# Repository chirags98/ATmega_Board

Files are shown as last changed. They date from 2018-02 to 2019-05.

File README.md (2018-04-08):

# ATmega_Board
This is a design to create a general purpose uC board using a ATmega328p microcontroller

Find the BOM (Bill of materials) on https://drive.google.com/open?id=1ma9ChhY5GpuYgg1Ucf6gE6C5UKoa5oTefCcq_7sxWGw

Find the Documentation of the board on https://drive.google.com/open?id=1ZgfvmyehAIBZDk0_nPWmhZg0xXYO81bvEzHlQfDXWbA

Find the example codes on https://github.com/chirags98/ATmega328-Example-Codes

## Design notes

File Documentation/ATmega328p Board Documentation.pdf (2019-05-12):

# ATmega Board Documentation

Objective | 2
Features | 2
Overview of using the board | 3
How to upload the Blink code for the first time | 3
Installing Atmel Studio | 3
Installing the drivers for USBasp | 4
Option 1: With Zadig | 4
Option 2: Without Zadig | 4
USBasp programmer | 5
Programming using SinaProg | 5
Programming with Arduino | 6
Steps to program using Arduino IDE | 6
Steps to burning the bootloader | 6
Serial Communication | 7
Installing FTDI driver | 7
Fuse settings on a new ATmega 328p | 8
ATmega to LCD mapping | 8
ATmega board to Arduino mapping | 8
Chirag Shah | 08/Apr/2018 | 1

# Objective

The objective of this document is to give an overview of the ATmega board, what all software installations and pin configurations one should be aware off so that one can get started with using the board.

# Features

1. ATmega 328p microcontroller
2. Serial (Arduino) as well as ISP programmable
3. Onboard 3.3v regulator
4. Onboard 5v regulator
5. Input voltage range: 7-20v using the DC Jack
6. Port for and onboard 16x2 LCD

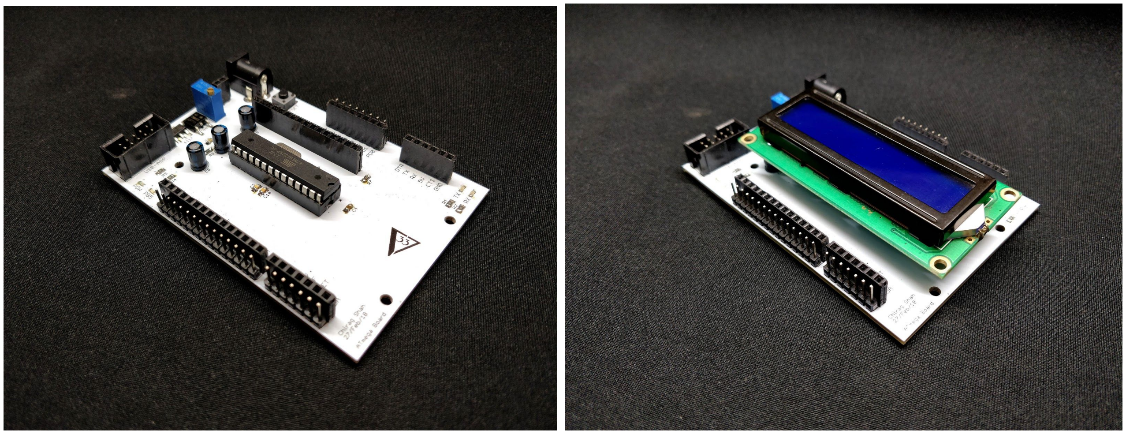
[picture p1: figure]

You can get the PCB design on https://github.com/chirags98/ATmega_Board

You can get the example codes for Atmel Studio on https://github.com/chirags98/ATmega328-Example-Codes

# Using the board

General instructions to use the board after the initial setup is complete are (detailed first-time instructions given below)
1. Write your code in Atmel studio (or use the example codes)
2. Build the solution to generate the hex file
3. Program the hex file on the board using USBasp programmer and SinaProg software (USBasp driver should be installed on the computer).

If you want to program the microcontroller using Arduino IDE, then
1. Write your code in the Arduino IDE
2. Select Arduino Nano and the COM port
3. Upload the code on the board using FTDI USB to Serial converter

Connect the FTDI directly to the header on the board ensuring that the pinout of the FTDI matches with the pinout on the board. Rx goes to Tx and Tx goes to Rx.

ATmega microcontroller should have the Arduino Nano bootloader on it. FTDI drivers should be installed.

# Uploading the Blink code for the first time

1. Download the example codes from here (https://github.com/chirags98/ATmega_Board)
2. You will need to download and install Atmel studio for writing new codes and to update existing codes (Procedure)
3. Disable the device driver signature enforcement and install the drivers for USB-ASP (Procedure)
4. Download SinaProg to upload the hex file to the microcontroller (Procedure)
5. Check the USB-ASP jumper (Procedure)
6. Upload the hex file. The hex file will be located in Blink>Blink>Debug>Blink.hex (Procedure)

## Installing Atmel Studio

Atmel Studio is the recommended IDE for embedded C programming for AVR microcontrollers.
Download and install the latest version from https://www.microchip.com/avr-support/atmel-studio-7

While installing only select support for 8-bit AVR microcontrollers.

## Installing the drivers for USBasp

### Option 1: With Zadig

1. Download Zadig software from http://chiragrshah.com/zadig_download Or from
https://zadig.akeo.ie/
2. Unzip and run zadig-2.4.exe
3. Click on Options>list all device
4. Select USBASP from the list
5. Select and install libusbK driver

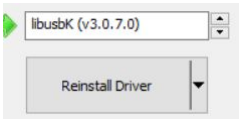
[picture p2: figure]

6. If this does not work try other drivers than libusbK

### Option 2: Without Zadig

The drivers for USPasp programmer are not digitally signed thus for security purposes windows has blocked the installation of unsigned drivers.

Get the USPasp drivers from https://drive.google.com/open?id=1goBblAIIR3vfRTkgHP2Q47yjxqCTrpaF

To disable the Driver Signature Enforcement for installing and using the drivers follow the steps given below
1. Recovery
2. Advanced startup>Restart Now
3. Troubleshoot
4. Advanced Options
5. Startup Settings
6. Restart
7. Disable Driver Signature Enforcement (press 7)

Use the steps given below for installing the drivers
1. Device Manager
2. USBasp

3. Update Driver
4. Browse my computer for driver software
5. Navigate and select the libusb_0.1.12.1 folder. (use libusb_0.1.10.1 if this doesn't work)
If the programmer stops working occasionally then you might need to disable the drivers again.

## USBasp programmer

1. Make sure the “Slow SCK” jumper is removed if available on your programmer
2. Make sure the switch/jumper is set to 5v and not 3.3v
3. Make sure the drivers are installed before trying to use the programmer

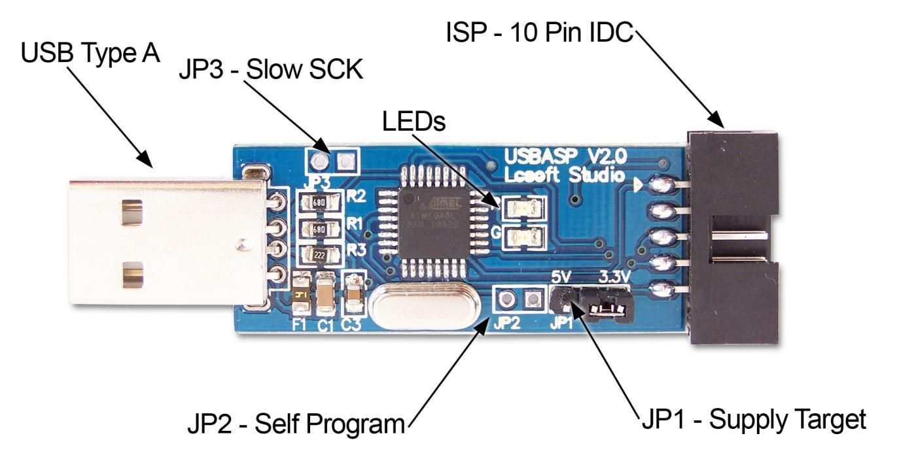
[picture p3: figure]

## Programming using SinaProg

Download SinaProg from
http://chiragrshah.com/download_sinaprog
1. Open the folder and run the application
2. Navigate to and select the .hex file of the project
3. Click on “Program flash”

# Programming with Arduino

This board can act exactly like an Arduino uno/nano. To program it with Arduino IDE make sure the microcontroller has bootloader on it. You cannot program it using an FTDI converter if it does not have a bootloader on it. To burn the bootloader follow the steps given below.

## Steps to program using Arduino IDE

1. Write your code in the Arduino IDE
2. Select Arduino Nano and the COM port
3. Connect the FTDI directly to the header on the board ensuring that the pinout of the FTDI matches with the pinout on the board. Rx goes to Tx and Tx goes to Rx.
4. Click on upload

Note: ATmega microcontroller should have the Arduino Nano bootloader on it. FTDI drivers should be installed.

## Steps to burning the bootloader

If you have a new ATmega328, you'll need to burn the bootloader onto it. You can do this using an Arduino board as an in-system program (ISP).
If the microcontroller already has the bootloader on it, you can skip this section.

To burn the bootloader, follow these steps:
1. Upload the ArduinoISP sketch onto your Arduino board. (You'll need to select the board and serial port from the Tools menu that correspond to your board.)
2. Connect the pins on Arduino to the pins on atmega board as shown on the table
3. Select "Arduino Duemilanove or Nano w/ ATmega328" from the Tools > Board menu.
4. Select "Arduino as ISP" from Tools > Programmer
5. Run Tools > Burn Bootloader
Pin on Arduino | Pin on target ATmega board
D13 | PB5
D12 | PB4
D11 | PB3
D10 | RESET
5V | 5V
GND | GND

Option 2: Use another ATmega board instead of an Arduino

Pin on master ATmega board | Pin on target ATmega board
PB5 | PB5
PB4 | PB4
PB3 | PB3
PB2 | RESET
5V | 5V
GND | GND

Further reference for this can be found at: https://www.Arduino.cc/en/Tutorial/ArduinoToBreadboard

## Serial Communication

If you want to interface your ATmega board to your computer via USB you will need a FTDI USB To TTL Serial Converter Adapter Module.

Your PC can communicate with the board via the serial port (also known as a UART or USART Serial). It communicates on digital pins 0 (RX) and 1 (TX) as well as with the computer via USB.

## Installing FTDI driver

FTDI USB to serial converter is required for USB to serial communication. Download the FTDI driver from http://www.ftdichip.com/Drivers/VCP.htm

# Fuse settings on a new ATmega 328p

If you are using a new ATmega IC you will need to program the fuse bits the first time.

The recommended settings for the fuse bits are
Lock Bits | x0F
High Fuse | xDA
Low fuse | xFF
Ext. Fuse | x05

Steps to program the fuse bits
1. Open SinaProg
2. Fuses > Advanced
3. Set the correct values and write (Try once again if you get a verification error) References:
http://www.engbedded.com/fusecalchttp://www.martyncurrey.com/Arduino-atmega-328p-fuse-settings/

# ATmega to LCD mapping

ATmega Board | LCD
PD2 | D7
PD3 | D6
PD4 | D5
PD5 | D4
PD6 | E
PD7 | RS

# ATmega board to Arduino mapping

This section gives the pin mappings between the ATmega to Arduino board
ATmega Board | Arduino
PD0/RX | D0/RX

PD1/TX | D1/TX
PD2 | D2
PD3 | D3
PD4 | D4
PD5 | D5
PD6 | D6
PD7 | D7
ATmega Board | Arduino
PC0 | A0
PC1 | A1
PC2 | A2
PC3 | A3
PC4/SDA | A4
PC5/SCL | A5
ATmega Board | Arduino
PB0 | D8
PB1 | D9
PB2 | D10
PB3/MOSI | D11
PB4/MISO | D12
PB5/SCK | D13

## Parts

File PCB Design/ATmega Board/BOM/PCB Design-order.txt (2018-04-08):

Order list for C:/Users/Chirag/Desktop/ATmega Design/ATmega_Board/PCB Design/ATmega Board/PCB Design.sch
Exported from EAGLE with DesignLink

Quantity	Value	Package	Order code	Manufacturer	Manuf. Code	Availability	Price (from)	Description
1	POWER_JACK	POWER_JACK_PTH	1310918	MULTICOMP	SPC21365	4534	75.3	MULTICOMP - SPC21365 - CONNECTOR, DC POWER, JACK, 5A
1	V_REG_LD1117VXXLD1117-SMD	SOT223	unknown					
1	5V	TO-252	unknown					
1	ATMEGA328P-PU	DIP254P762X457-28	1715487	MICROCHIP	ATMEGA328P-PU	823	120.45	MICROCHIP - ATMEGA328P-PU - MCU, 8BIT, ATMEGA, 20MHZ, DIP-28
3	10uf	E2,5-6	unknown					
3	.1uF	C0805K	unknown					
1	0.33µF	C0805K	unknown					
2	22pF	C0805K	unknown					
1	.1uf	C0805K	unknown					
1	50k	S64W	unknown					
1		1X02	unknown					
1		2X08	unknown					
2		2X06	unknown					
1		2X03	unknown					
1		2X07	unknown					
1	LCD-16X2NOSILK	LCD-16X2_NOSILK	unknown					
1	BLUE	LED-0603	unknown					
1	RED	LED-0603	unknown					
1	16MHz	HC49U70	unknown					
4	330	M0805	unknown					
1	10k	M0805	unknown					
1	220	M0805	unknown					
1		B3F-10XX	176432	OMRON ELECTRONIC COMPONENTS	B3F-1000	35652	14.54	OMRON ELECTRONIC COMPONENTS - B3F-1000 - SWITCH, SPNO, 0.05A, 24V, THT, 0.98N
2	Yellow	LED-0603	unknown					
1	6_PIN_SERIAL_CABLEPTH	FTDI_BASIC	unknown					
1	AVR_SPI_PROG_5X2PTH2	2X5-SHROUDED	unknown

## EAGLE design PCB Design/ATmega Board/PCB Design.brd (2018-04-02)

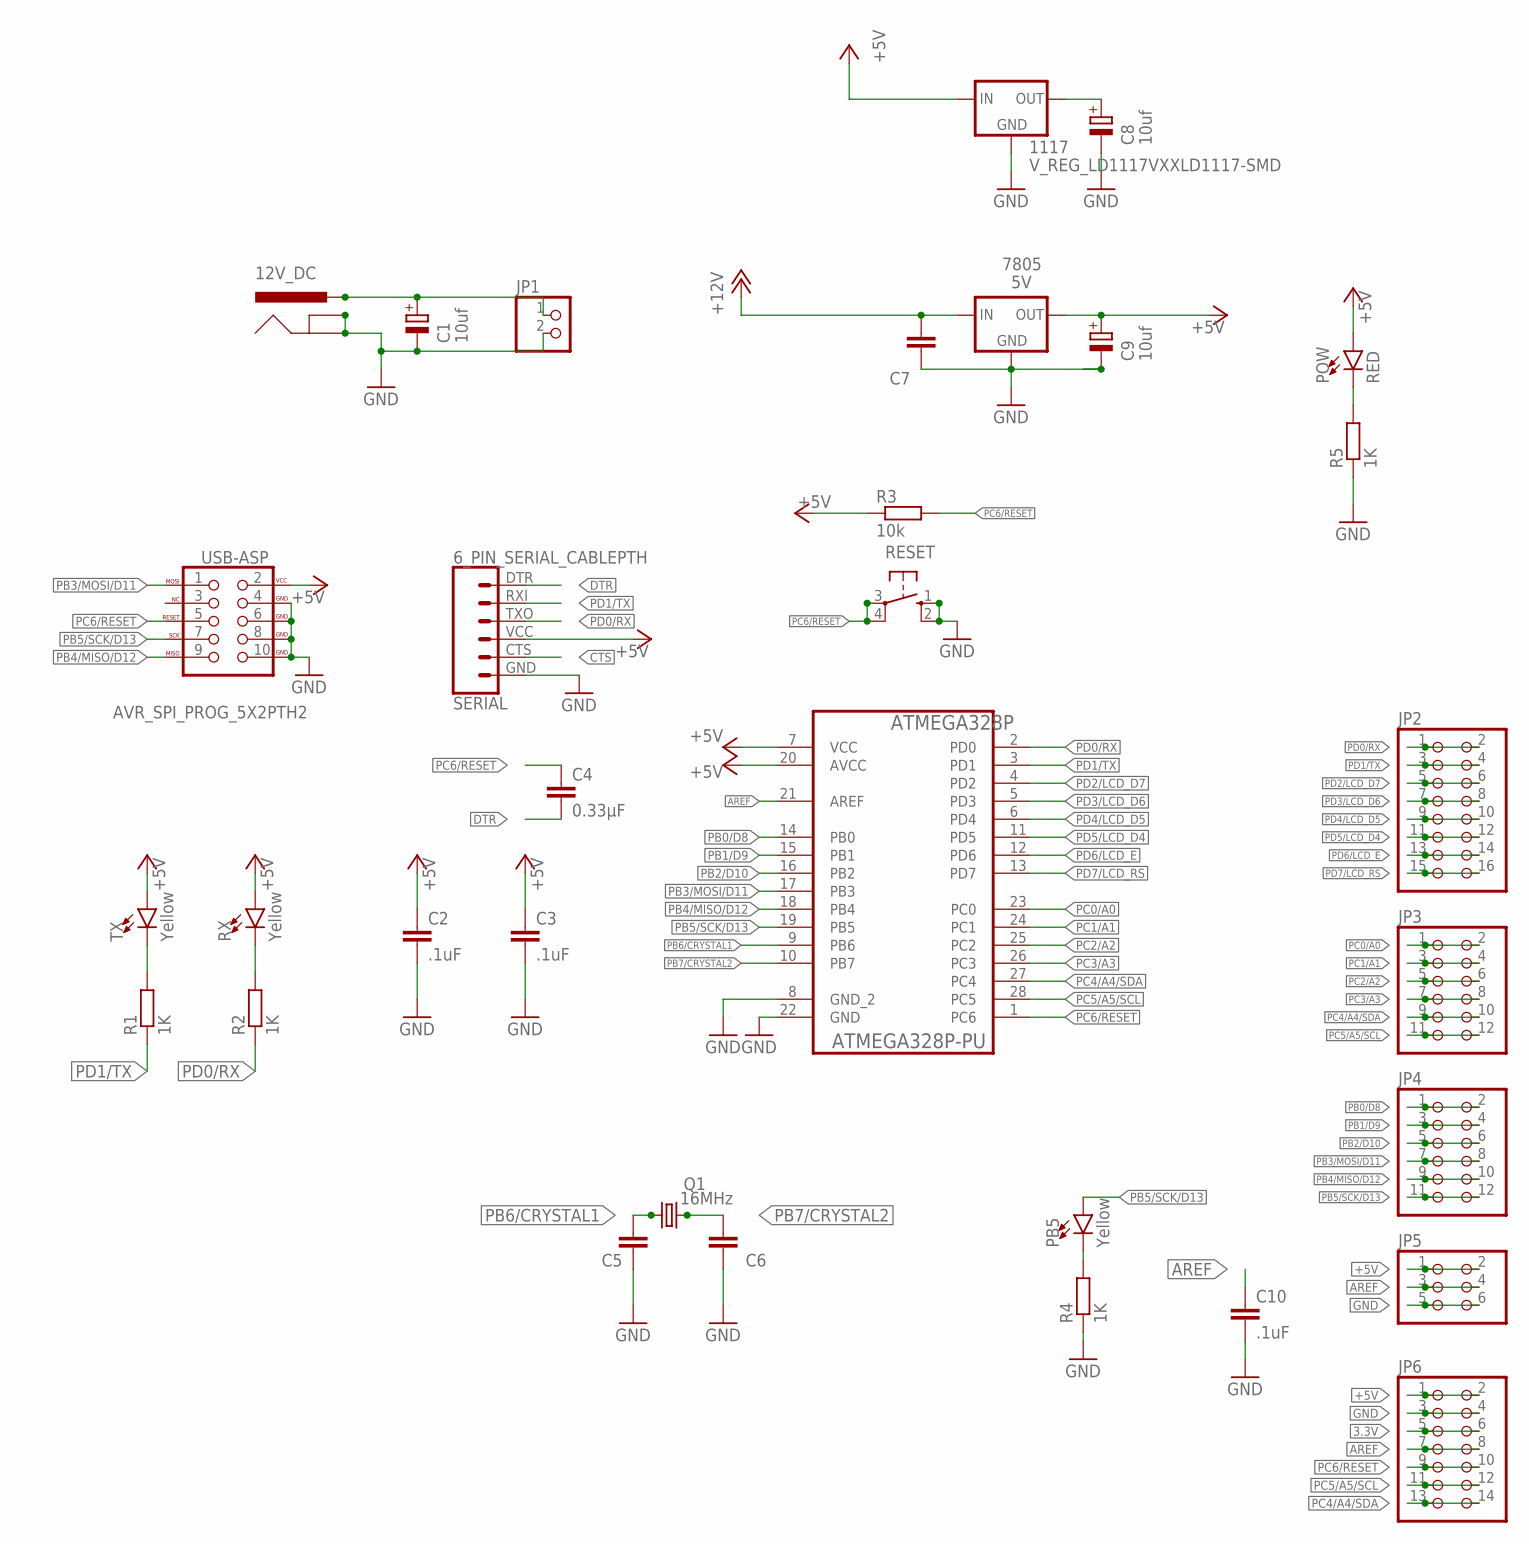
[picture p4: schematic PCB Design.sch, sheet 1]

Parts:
12V_DC: POWER_JACK; POWER_JACK_PTH; MPN SPC21365
1117: V_REG_LD1117VXXLD1117-SMD; SOT223
7805: 5V; TO-252
ATMEGA328P: ATMEGA328P-PU; DIP254P762X457-28
C1, C8, C9: 10uf; E2,5-6
C2, C3, C10: .1uF; C0805K
C4: 0.33µF; C0805K
C5, C6: 22pF; C0805K
C7: .1uf; C0805K
JP1: PINHD-1X2; 1X02
JP2: PINHD-2X8; 2X08
JP3, JP4: PINHD-2X6; 2X06
JP5: PINHD-2X3; 2X03
JP6: PINHD-2X7; 2X07
PB5: Yellow; LED-0603
POW: RED; LED-0603
Q1: 16MHz; HC49U70
R1, R2, R4, R5: 1K; M0805
R3: 10k; M0805
RESET: 10-XX; B3F-10XX
RX: Yellow; LED-0603
SERIAL: 6_PIN_SERIAL_CABLEPTH; FTDI_BASIC
TX: Yellow; LED-0603
USB-ASP: AVR_SPI_PROG_5X2PTH2; 2X5-SHROUDED

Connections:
3.3V: 1117.2 (OUT), C8.+, JP6.5, JP6.6
+5V: 1117.3 (IN), 7805.2 (OUT), ATMEGA328P.7 (VCC), ATMEGA328P.20 (AVCC), C2.1, C3.1, C9.+, JP5.1, JP5.2, JP6.1, JP6.2, POW.A, R3.1, RX.A, SERIAL.VCC (4), TX.A, USB-ASP.2 (VCC); also elsewhere on the board
+12V: 12V_DC.PWR, 7805.1 (IN), C1.+, C7.1, JP1.1
AREF: ATMEGA328P.21 (AREF), C10.1, JP5.3, JP5.4, JP6.7, JP6.8
CTS: SERIAL.CTS (5)
DTR: C4.2, SERIAL.DTR (1)
GND: 12V_DC.GND, 12V_DC.GNDBREAK, 1117.1 (GND), 7805.3 (GND), ATMEGA328P.8 (GND_2), ATMEGA328P.22 (GND), C1.-, C2.2, C3.2, C5.1, C6.1, C7.2, C8.-, C9.-, C10.2, JP1.2, JP5.5, JP5.6, JP6.3, JP6.4, R4.1, R5.1, RESET.1 (S), RESET.2 (S1), SERIAL.GND (6), USB-ASP.4 (GND), USB-ASP.6 (GND), USB-ASP.8 (GND), USB-ASP.10 (GND); also elsewhere on the board
unnamed: PB5.C, R4.2
unnamed: POW.C, R5.2
unnamed: R2.2, RX.C
unnamed: R1.2, TX.C
PB0/D8: ATMEGA328P.14 (PB0), JP4.1, JP4.2
PB1/D9: ATMEGA328P.15 (PB1), JP4.3, JP4.4
PB2/D10: ATMEGA328P.16 (PB2), JP4.5, JP4.6
PB3/MOSI/D11: ATMEGA328P.17 (PB3), JP4.7, JP4.8, USB-ASP.1 (MOSI)
PB4/MISO/D12: ATMEGA328P.18 (PB4), JP4.9, JP4.10, USB-ASP.9 (MISO)
PB5/SCK/D13: ATMEGA328P.19 (PB5), JP4.11, JP4.12, PB5.A, USB-ASP.7 (SCK)
PB6/CRYSTAL1: ATMEGA328P.9 (PB6), C5.2, Q1.1
PB7/CRYSTAL2: ATMEGA328P.10 (PB7), C6.2, Q1.2
PC0/A0: ATMEGA328P.23 (PC0), JP3.1, JP3.2
PC1/A1: ATMEGA328P.24 (PC1), JP3.3, JP3.4
PC2/A2: ATMEGA328P.25 (PC2), JP3.5, JP3.6
PC3/A3: ATMEGA328P.26 (PC3), JP3.7, JP3.8
PC4/A4/SDA: ATMEGA328P.27 (PC4), JP3.9, JP3.10, JP6.13, JP6.14
PC5/A5/SCL: ATMEGA328P.28 (PC5), JP3.11, JP3.12, JP6.11, JP6.12
PC6/RESET: ATMEGA328P.1 (PC6), C4.1, JP6.9, JP6.10, R3.2, RESET.3, RESET.4 (P1), USB-ASP.5 (RESET)
PD0/RX: ATMEGA328P.2 (PD0), JP2.1, JP2.2, R2.1, SERIAL.TXO (3)
PD1/TX: ATMEGA328P.3 (PD1), JP2.3, JP2.4, R1.1, SERIAL.RXI (2)
PD2/LCD_D7: ATMEGA328P.4 (PD2), JP2.5, JP2.6; also elsewhere on the board
PD3/LCD_D6: ATMEGA328P.5 (PD3), JP2.7, JP2.8; also elsewhere on the board
PD4/LCD_D5: ATMEGA328P.6 (PD4), JP2.9, JP2.10; also elsewhere on the board
PD5/LCD_D4: ATMEGA328P.11 (PD5), JP2.11, JP2.12; also elsewhere on the board
PD6/LCD_E: ATMEGA328P.12 (PD6), JP2.13, JP2.14; also elsewhere on the board
PD7/LCD_RS: ATMEGA328P.13 (PD7), JP2.15, JP2.16; also elsewhere on the board

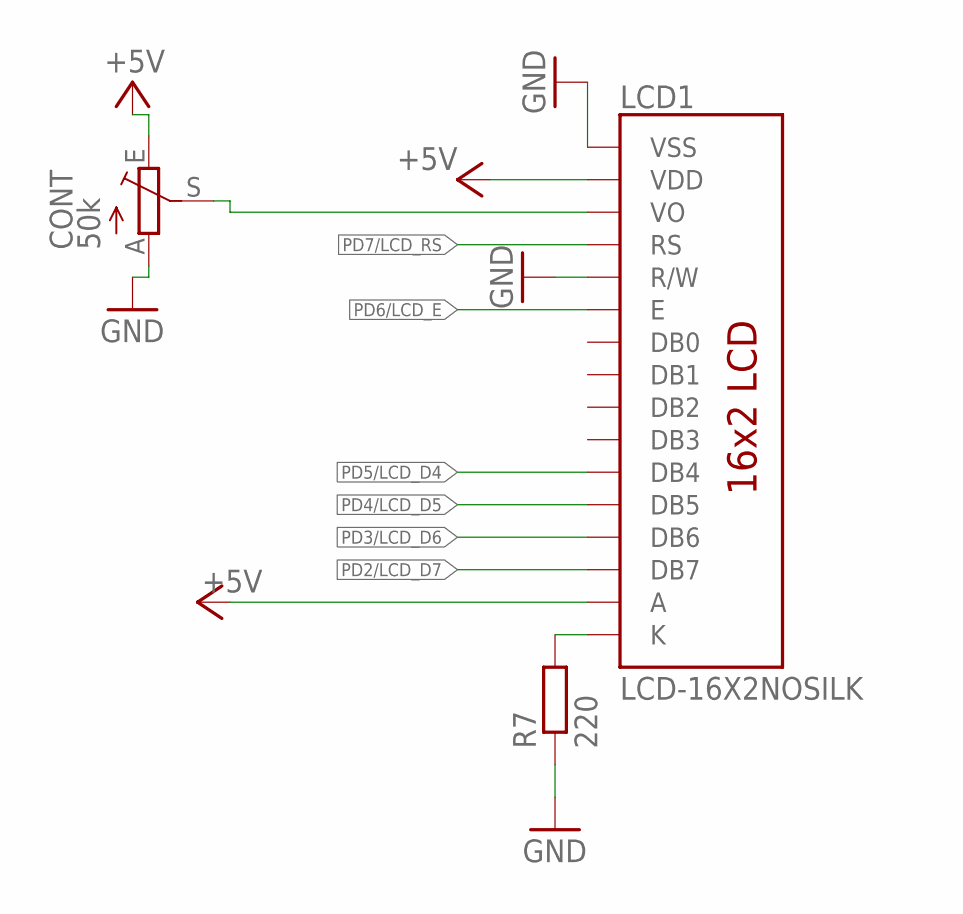
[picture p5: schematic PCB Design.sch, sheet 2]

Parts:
CONT: 50k; S64W
LCD1: LCD-16X2NOSILK; LCD-16X2_NOSILK
R7: 220; M0805

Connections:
+5V: CONT.E, LCD1.2 (VDD), LCD1.15 (A); also elsewhere on the board
GND: CONT.A, LCD1.1 (VSS), LCD1.5 (R/W), R7.1; also elsewhere on the board
unnamed: CONT.S, LCD1.3 (VO)
unnamed: LCD1.16 (K), R7.2
PD2/LCD_D7: LCD1.14 (DB7); also elsewhere on the board
PD3/LCD_D6: LCD1.13 (DB6); also elsewhere on the board
PD4/LCD_D5: LCD1.12 (DB5); also elsewhere on the board
PD5/LCD_D4: LCD1.11 (DB4); also elsewhere on the board
PD6/LCD_E: LCD1.6 (E); also elsewhere on the board
PD7/LCD_RS: LCD1.4 (RS); also elsewhere on the board

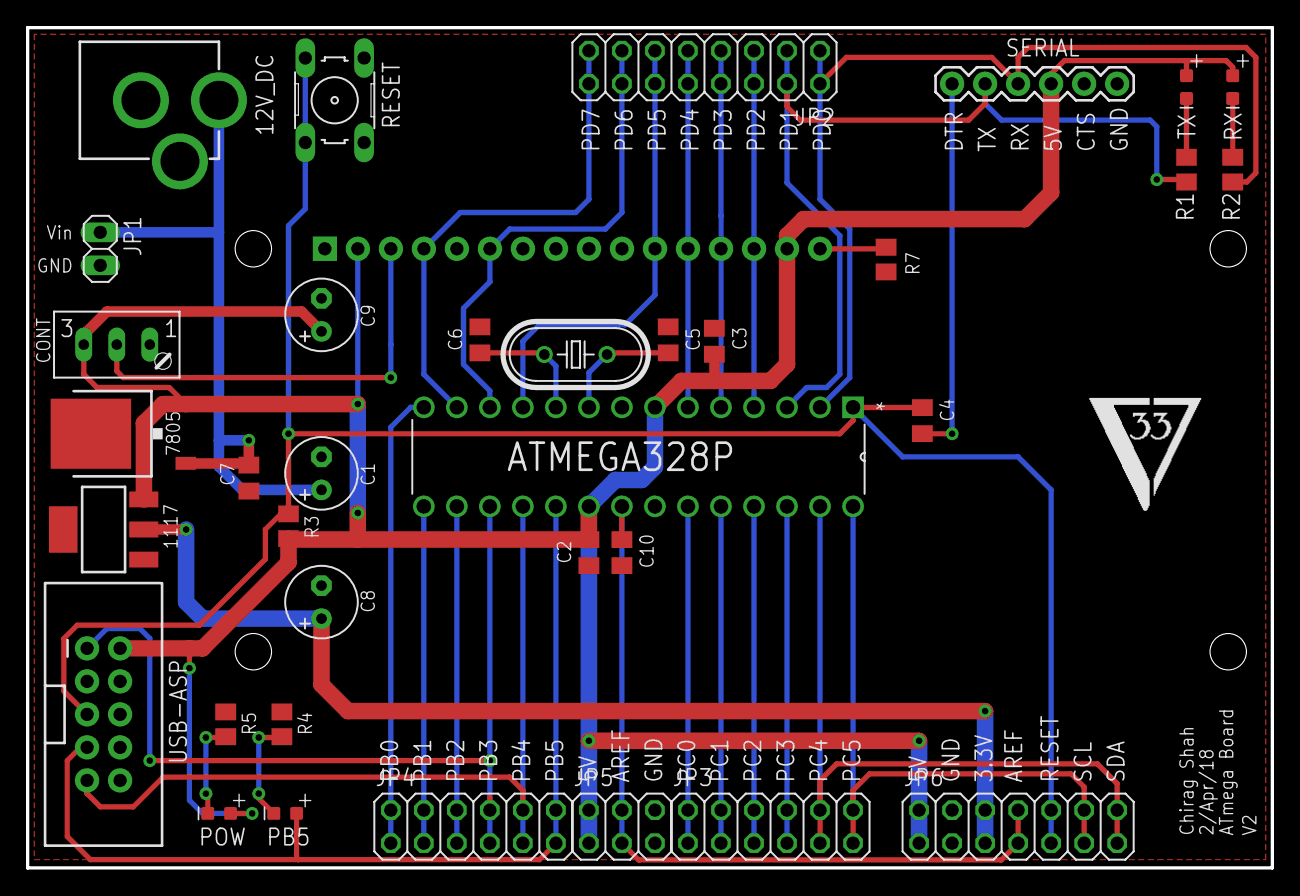
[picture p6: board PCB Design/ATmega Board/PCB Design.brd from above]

Board: 2 copper layers, 95.8 x 64.6 mm, 36 parts (0 on the bottom side), 35 nets.

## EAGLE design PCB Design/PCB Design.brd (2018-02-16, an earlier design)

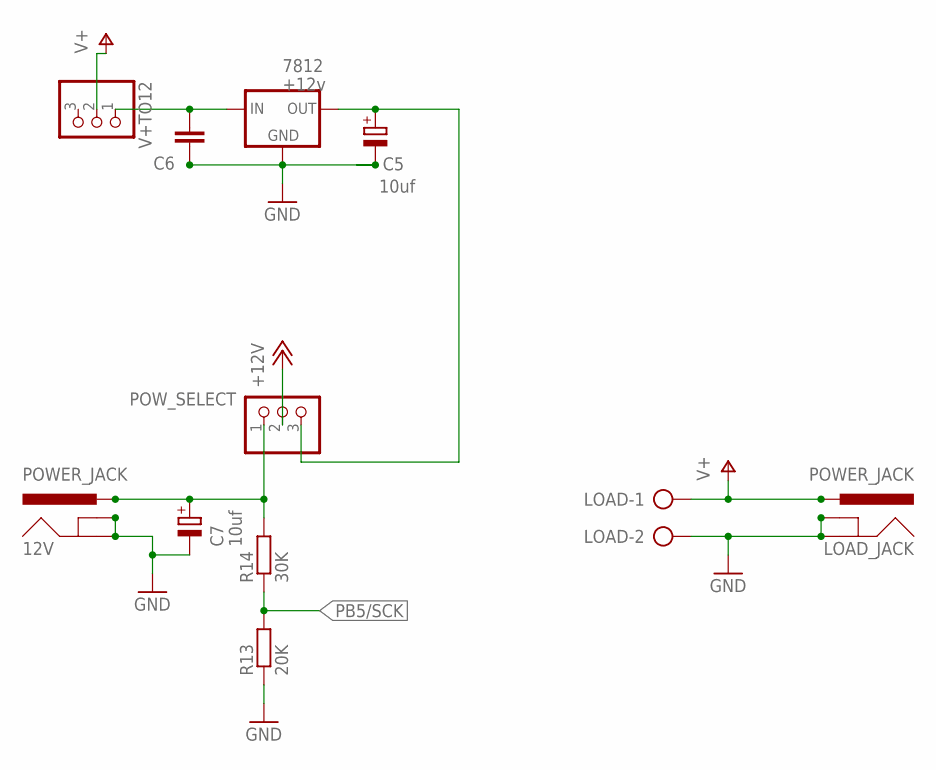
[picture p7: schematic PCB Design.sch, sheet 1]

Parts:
12V: POWER_JACK; POWER_JACK_PTH
7812: +12v; TO-252
C5, C7: 10uf; E2,5-6
C6: .1uF; C0805K
LOAD: AK500/2-H
LOAD_JACK: POWER_JACK; POWER_JACK_PTH
POW_SELECT: PINHD-1X3; 1X03
R13: 20K; M0805
R14: 30K; M0805
V+TO12: PINHD-1X3; 1X03

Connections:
12V_JACK_INPUT: 12V.PWR, C7.+, POW_SELECT.1, R14.2
12V_REG_O/P: 7812.2 (OUT), C5.+, POW_SELECT.3
+12V: POW_SELECT.2; also elsewhere on the board
GND: 12V.GND, 12V.GNDBREAK, 7812.3 (GND), C5.-, C6.2, C7.-, LOAD.2, LOAD_JACK.GND, LOAD_JACK.GNDBREAK, R13.1; also elsewhere on the board
unnamed: 7812.1 (IN), C6.1, V+TO12.1
PB5/SCK: R13.2, R14.1; also elsewhere on the board
V+: LOAD.1, LOAD_JACK.PWR, V+TO12.2

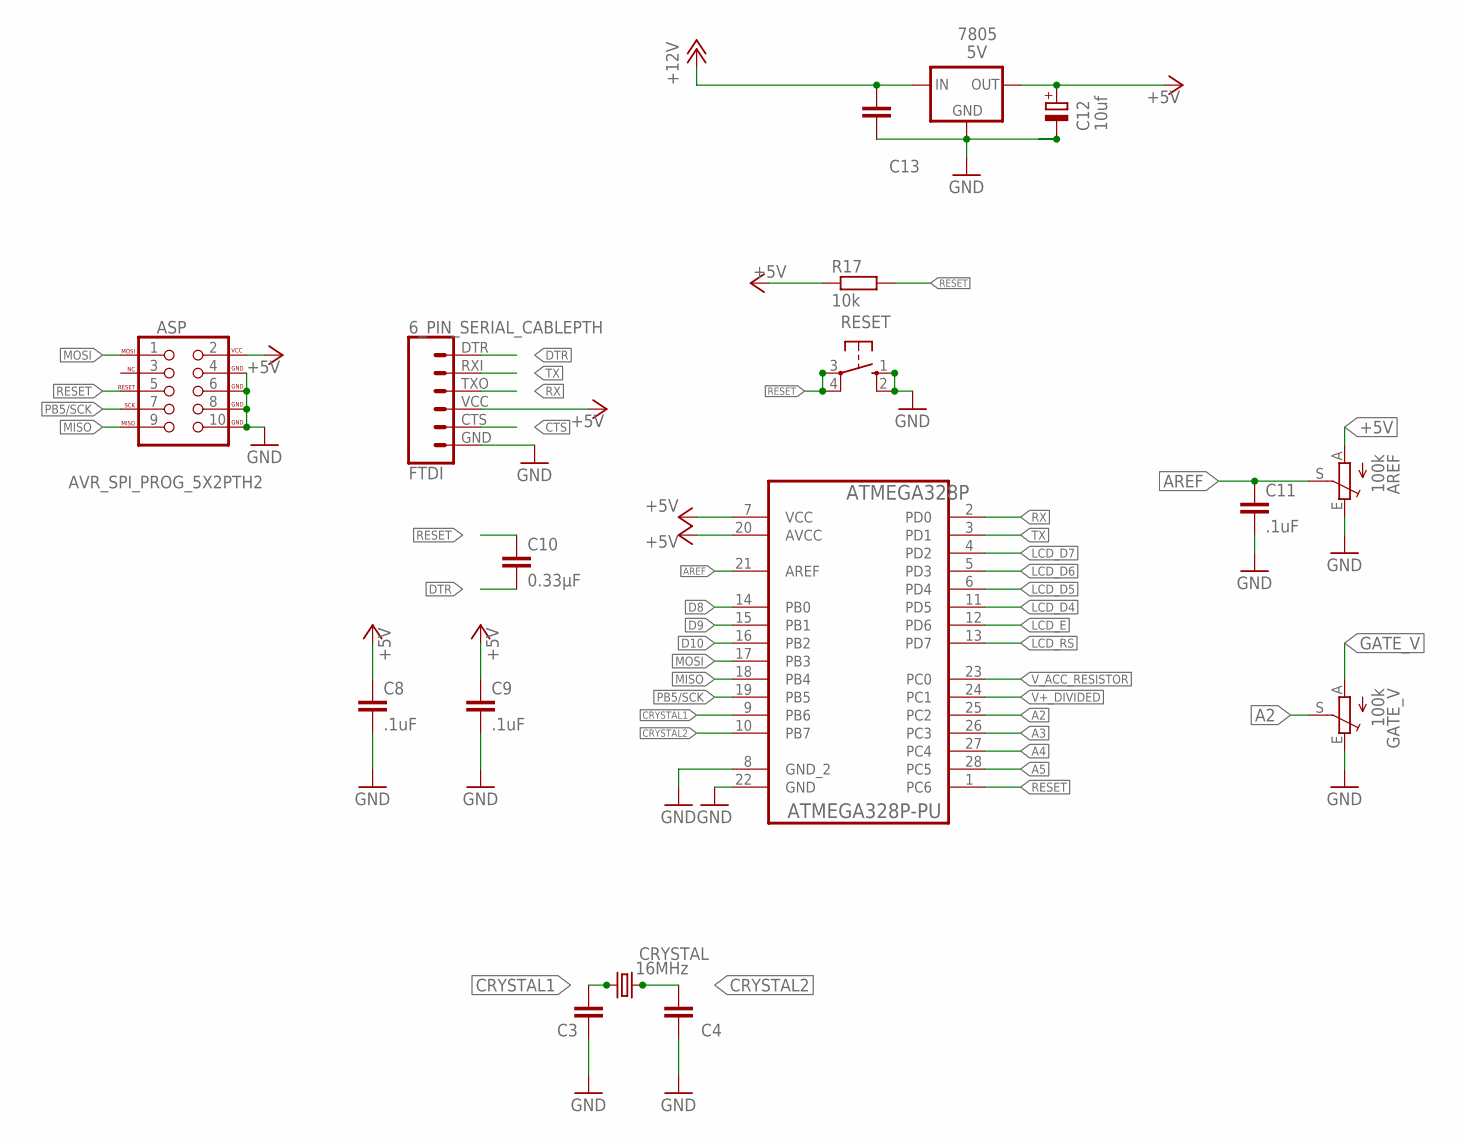
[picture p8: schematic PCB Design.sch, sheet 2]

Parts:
7805: 5V; TO-252
AREF: 100k; S64W
ASP: AVR_SPI_PROG_5X2PTH2; 2X5-SHROUDED
ATMEGA328P: ATMEGA328P-PU; DIP254P762X457-28
C3, C4: 22pF; C0805K
C8, C9, C11: .1uF; C0805K
C10: 0.33µF; C0805K
C12: 10uf; E2,5-6
C13: .1uf; C0805K
CRYSTAL: 16MHz; HC49U70
FTDI: 6_PIN_SERIAL_CABLEPTH; FTDI_BASIC
GATE_V: 100k; S64W
R17: 10k; M0805
RESET: 10-XX; B3F-10XX

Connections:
+5V: 7805.2 (OUT), AREF.A, ASP.2 (VCC), ATMEGA328P.7 (VCC), ATMEGA328P.20 (AVCC), C8.1, C9.1, C12.+, FTDI.VCC (4), R17.1; also elsewhere on the board
+12V: 7805.1 (IN), C13.1; also elsewhere on the board
A2: ATMEGA328P.25 (PC2), GATE_V.S
A3: ATMEGA328P.26 (PC3)
A4: ATMEGA328P.27 (PC4)
A5: ATMEGA328P.28 (PC5)
AREF: AREF.S, ATMEGA328P.21 (AREF), C11.1
CRYSTAL1: ATMEGA328P.9 (PB6), C3.2, CRYSTAL.1
CRYSTAL2: ATMEGA328P.10 (PB7), C4.2, CRYSTAL.2
CTS: FTDI.CTS (5)
D8: ATMEGA328P.14 (PB0)
D9: ATMEGA328P.15 (PB1)
D10: ATMEGA328P.16 (PB2)
DTR: C10.2, FTDI.DTR (1)
GATE_V: GATE_V.A
GND: 7805.3 (GND), AREF.E, ASP.4 (GND), ASP.6 (GND), ASP.8 (GND), ASP.10 (GND), ATMEGA328P.8 (GND_2), ATMEGA328P.22 (GND), C3.1, C4.1, C8.2, C9.2, C11.2, C12.-, C13.2, FTDI.GND (6), GATE_V.E, RESET.1 (S), RESET.2 (S1); also elsewhere on the board
LCD_D4: ATMEGA328P.11 (PD5); also elsewhere on the board
LCD_D5: ATMEGA328P.6 (PD4); also elsewhere on the board
LCD_D6: ATMEGA328P.5 (PD3); also elsewhere on the board
LCD_D7: ATMEGA328P.4 (PD2); also elsewhere on the board
LCD_E: ATMEGA328P.12 (PD6); also elsewhere on the board
LCD_RS: ATMEGA328P.13 (PD7); also elsewhere on the board
MISO: ASP.9 (MISO), ATMEGA328P.18 (PB4)
MOSI: ASP.1 (MOSI), ATMEGA328P.17 (PB3)
PB5/SCK: ASP.7 (SCK), ATMEGA328P.19 (PB5); also elsewhere on the board
RESET: ASP.5 (RESET), ATMEGA328P.1 (PC6), C10.1, R17.2, RESET.3, RESET.4 (P1)
RX: ATMEGA328P.2 (PD0), FTDI.TXO (3)
TX: ATMEGA328P.3 (PD1), FTDI.RXI (2)
V+_DIVIDED: ATMEGA328P.24 (PC1)
V_ACC_RESISTOR: ATMEGA328P.23 (PC0)

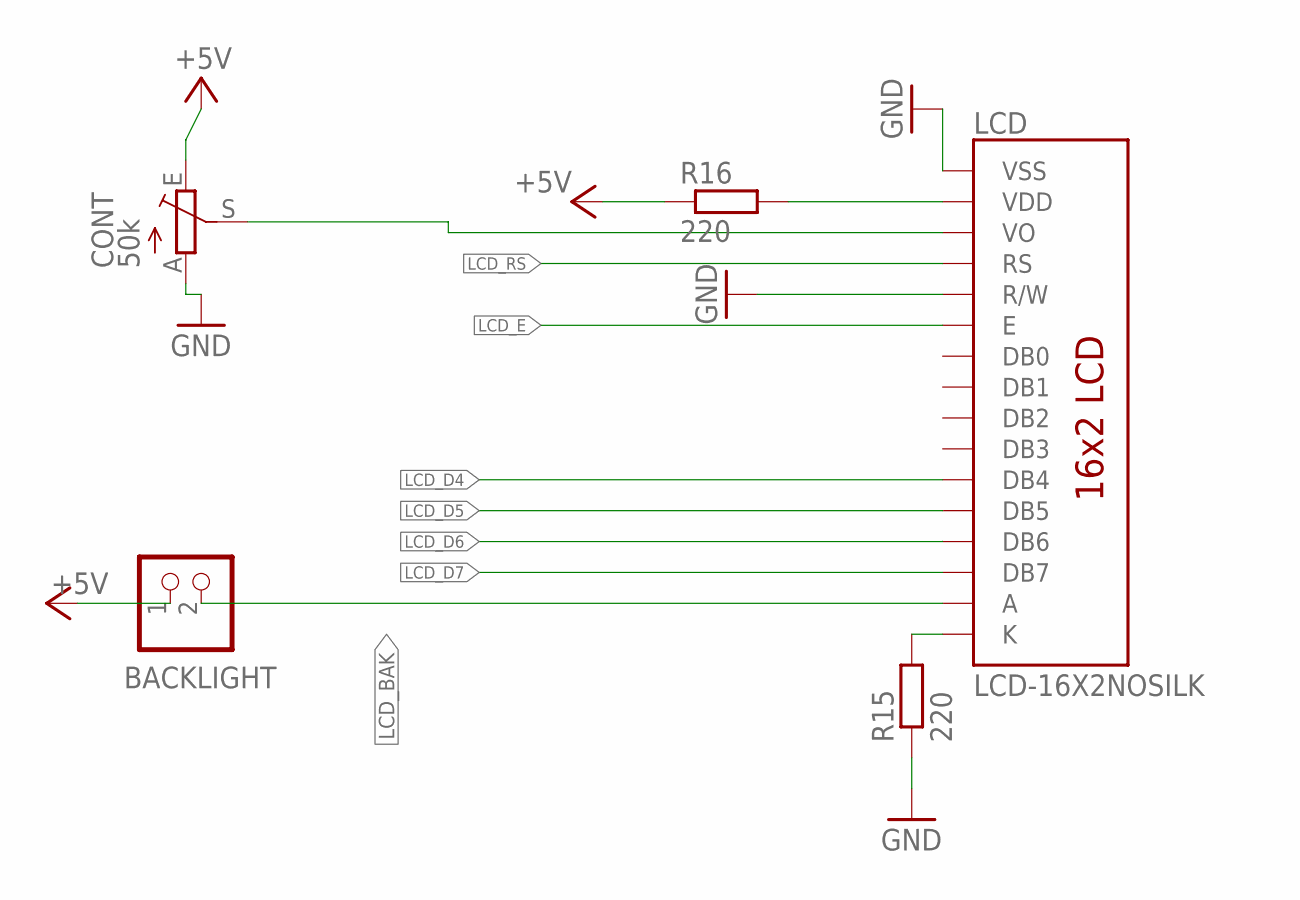
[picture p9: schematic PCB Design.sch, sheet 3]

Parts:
BACKLIGHT: PINHD-1X2; 1X02
CONT: 50k; S64W
LCD: LCD-16X2NOSILK; LCD-16X2_NOSILK
R15, R16: 220; M0805

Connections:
+5V: BACKLIGHT.1, CONT.E, R16.1; also elsewhere on the board
GND: CONT.A, LCD.1 (VSS), LCD.5 (R/W), R15.1; also elsewhere on the board
LCD_BAK: BACKLIGHT.2, LCD.15 (A)
LCD_D4: LCD.11 (DB4); also elsewhere on the board
LCD_D5: LCD.12 (DB5); also elsewhere on the board
LCD_D6: LCD.13 (DB6); also elsewhere on the board
LCD_D7: LCD.14 (DB7); also elsewhere on the board
LCD_E: LCD.6 (E); also elsewhere on the board
LCD_RS: LCD.4 (RS); also elsewhere on the board
unnamed: CONT.S, LCD.3 (VO)
unnamed: LCD.2 (VDD), R16.2
unnamed: LCD.16 (K), R15.2

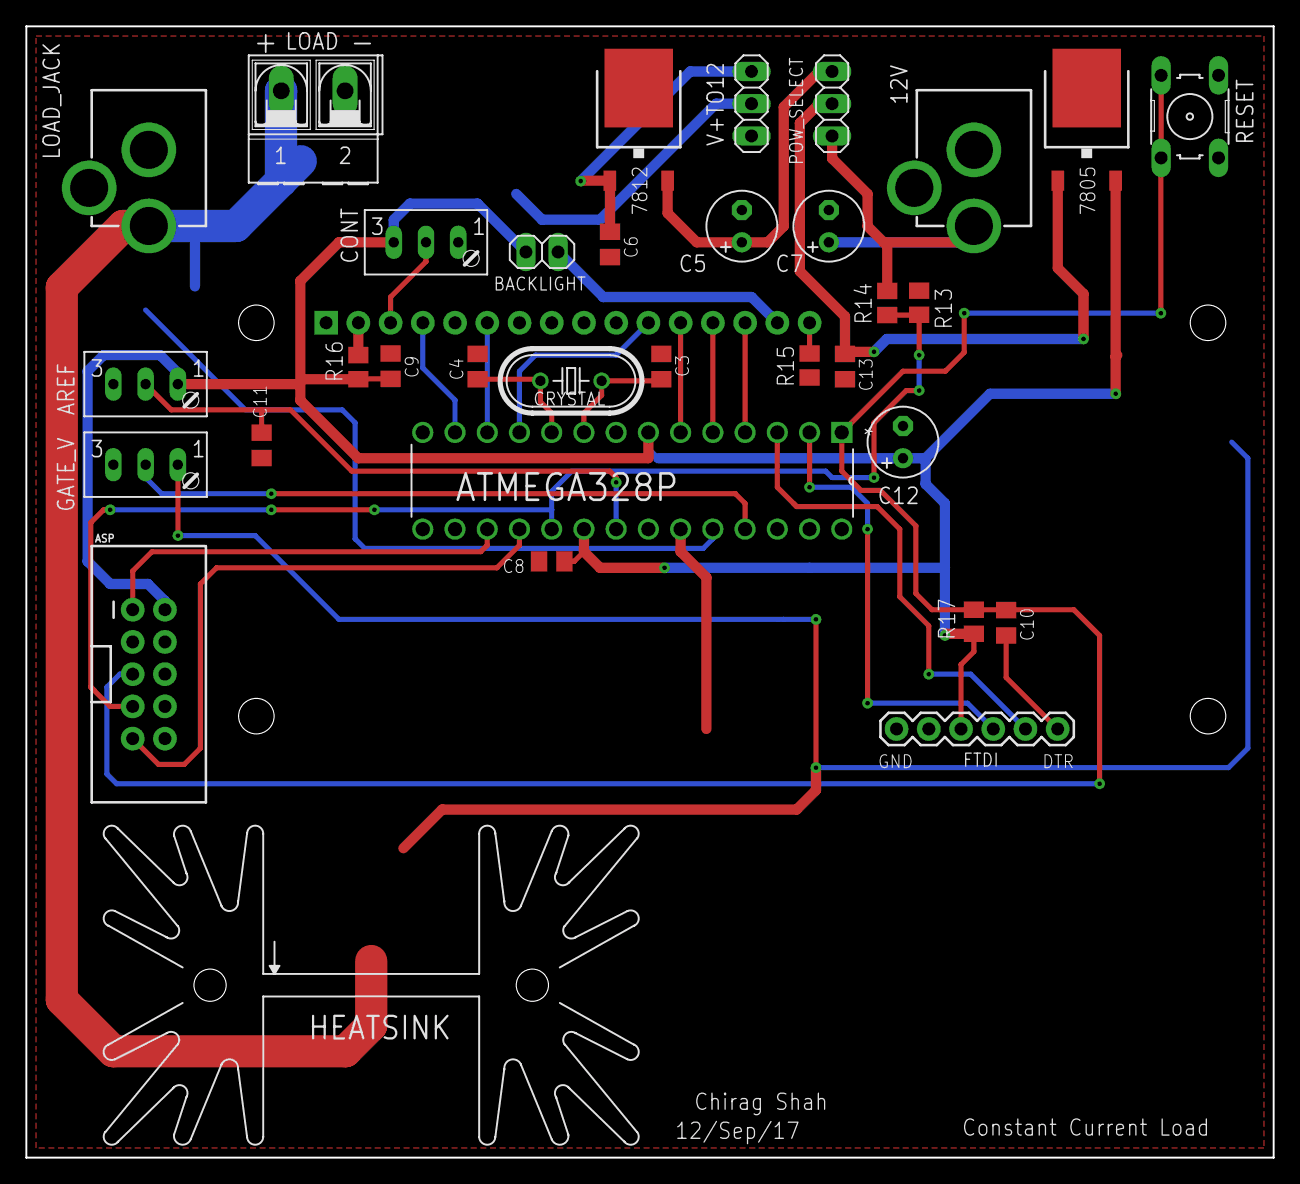
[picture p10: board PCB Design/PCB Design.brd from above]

Board: 2 copper layers, 98.3 x 89.2 mm, 34 parts (0 on the bottom side), 28 nets.

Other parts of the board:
HEATSINK: SK129-HOLE

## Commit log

2018-02-16 Made a folder for the PCB design and copied CCL design
    [PCB Design.brd, PCB Design.sch]
2018-02-16 Working on design
    [PCB Design.brd, PCB Design.sch]
2018-02-20 testing new branch
    [PCB Design.brd]
2018-02-20 worked on double sided board
    [PCB Design.brd, PCB Design.sch]
2018-02-24 Worked on routing and silkscreen
    [PCB Design.brd, PCB Design.sch]
2018-02-24 Before routing 3.3v reg
    [PCB Design.brd, PCB Design.sch]
2018-02-24 Before moving pin header
    [PCB Design.brd, PCB Design.sch]
2018-02-24 Corrected mistake and generated gerbers
    [PCB Design.brd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]
2018-02-26 Verified schematic
2018-02-27 Before renumbering parts
    [PCB Design.brd, PCB Design.sch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]
2018-03-26 Corrected Silkscreen
    [PCB Design.sch]
2018-04-02 Corrected mistakes, V2, Final
    [PCB Design.brd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]
2018-04-02 Zipped Final Gerbers
2018-04-08 Added BOM and updated Readme

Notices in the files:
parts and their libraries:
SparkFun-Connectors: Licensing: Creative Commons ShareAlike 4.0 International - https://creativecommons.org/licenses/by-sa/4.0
